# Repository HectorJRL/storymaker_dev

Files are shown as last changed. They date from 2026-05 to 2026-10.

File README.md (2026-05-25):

# StoryMaker

Dispositivo educativo basado en Raspberry Pi Zero 2W para talleres literarios.
Genera premisas narrativas aleatorias y las muestra por pantalla e-ink, impresora térmica o audio.

## Estado
En desarrollo activo. Este repo es el espacio de trabajo privado.

## Estructura
- `firmware/` — Código Python para la Raspberry Pi
- `hardware/` — STL, esquemas eléctricos, lista de componentes
- `docs/` — Manual, guías de montaje, imágenes
- `releases/` — Notas de versión

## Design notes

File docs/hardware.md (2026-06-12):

# Hardware — StoryMaker

## OS
Raspberry Pi OS Lite 64-bit Bookworm (estable)

## Pinout (BCM)
| Función | GPIO |
|---|---|
| Botón físico | 5 |
| LED estado | 23 |
| E-ink DC | 25 |
| E-ink RST | 17 |
| E-ink BUSY | 24 |
| E-ink SPI0 MOSI | 10 |
| E-ink SPI0 CLK | 11 |
| E-ink SPI0 CS0 | 8 |
| Impresora UART TX | 14 |
| Impresora UART RX | 15 |
| Audio I2S BCLK | 18 |
| Audio I2S LRCLK | 19 |
| Audio I2S DATA | 21 |

## Periféricos
- **E-ink:** WeAct 4.2" B&W (SSD1683) — refresco parcial NO soportado
- **Impresora:** QR701 UART térmica (ESC/POS, QR nativo GS(k) modelo 2)
- **Audio:** MAX98357A I2S — TTS edge-tts (es-ES-ElviraNeural) + mpg123
- **Fallback TTS offline:** espeak (voz local, entra cuando no hay red)

## LED (GPIO 23)
- Fijo encendido → sistema listo
- Parpadeo → feedback de pulsación
- Apagado → en proceso de shutdown

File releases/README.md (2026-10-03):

# Releases

Las imágenes distribuibles de StoryMaker (`storymaker-YYYY-MM-DD.img.xz`) **no se versionan en git**:
pesan alrededor de 1 GB. Se publican como **Release assets** en Codeberg. Sí se versiona el fichero
`.sha256` de cada una, que es diminuto y sirve para comprobar después que el adjunto publicado es el
que se generó aquí.

## Dónde descargar la imagen

**Codeberg es el único sitio de descarga.** Sección **Releases** del repositorio →
versión `vYYYY-MM-DD` → fichero `storymaker-YYYY-MM-DD.img.xz`.

`github.com/HectorJRL/storymaker_dev` es **espejo del código, no de las descargas**: los
push-mirrors de Codeberg replican refs de git, y la imagen nunca está en git (la ignora
`.gitignore`). Al espejo llegan los commits y los tags; el `.img.xz` no, porque no hay nada que
copiar.

Decidido así a propósito, y no por dejadez:

- No protege de nada que no esté ya cubierto. El código y la historia completa, tags incluidos, sí
  están en el espejo, y de un tag GitHub genera por su cuenta los `zip`/`tar.gz` del fuente. La
  receta para reconstruir cualquier imagen está duplicada; de la imagen en sí hay dos copias
  (Codeberg y el disco de desarrollo).
- Subir el adjunto al espejo sería un paso manual que nada obliga a repetir, así que se olvidaría
  en alguna release y quedarían unas versiones con descarga allí y otras sin ella: peor que
  ninguna, porque quien busque no sabrá si falta o si nunca se publicó.
- Dos sitios de descarga invitan a bajarse el viejo. El 2026-10-03 hubo que retirar una imagen
  defectuosa pocas horas después de publicarla; con una sola ubicación, retirarla basta.

Si Codeberg fallara: con el tag y el proceso descrito más abajo, la imagen se reconstruye.

## Credenciales de fábrica

| Credencial | De fábrica | Quién la cambia |
|---|---|---|
| PIN del portal web | `1234` | El usuario en el asistente de primer arranque (opcional) |
| Contraseña SSH de `storymaker` | `storymaker` | El usuario en el asistente de primer arranque (**obligatoria**) |

Son conocidas y públicas a propósito: el asistente no deja completar la configuración sin definir una
contraseña SSH propia, así que cada dispositivo acaba con la suya. Ver `docs/sistema.md`.

## Cómo publicar una release nueva

El orden importa. Lo que sigue es el proceso verificado el 2026-10-03.

### 1. Antes de tocar la imagen

```bash
git pull                                  # que no haya divergencia con el espejo
./deploy.sh <ip-de-la-pi>                 # el firmware debe ser el que vas a congelar
./deploy.sh --solo-firmware <ip-de-la-pi> # si sólo ha cambiado código Python
```

Desde v2026-10-03 las imágenes no traen el `NOPASSWD: ALL` de Raspberry Pi OS, así que instalar
ficheros de sistema pide la contraseña del dispositivo; ese paso usa `ssh -t` para que `sudo` tenga
terminal. Si sólo ha cambiado código Python —compruébalo con
`git diff --name-only <tag-de-la-imagen>..HEAD -- firmware/deploy/sistema/`— usa `--solo-firmware` y
te lo ahorras: reiniciar `historias.service` sí está en la lista corta de `/etc/sudoers.d`.

Prueba en el dispositivo lo que hayas cambiado. Una imagen se publica desde una Pi cuyo
comportamiento has visto funcionar, no desde una que asumes correcta.

### 2. Limpieza y captura

```bash
cd firmware/deploy
./crear_imagen.sh --local     # con la SD ya en el PC y la Pi apagada
./crear_imagen.sh <ip>        # o con la Pi encendida: limpia por SSH y la apaga
```

**Verifica la tarjeta antes de capturar.** Monta la raíz en sólo lectura y comprueba que no quedan
claves de host SSH, que `authorized_keys` y `.bash_history` están vacíos, que `010_pi-nopasswd` ha
desaparecido, que `storymaker-setpass` está instalado, que sólo queda el perfil de red del AP y que
`config.json` tiene `setup_completado: false`. Ese paso es el que detecta los fallos de limpieza; en
junio de 2026 no se hacía y la limpieza llevaba meses ejecutándose a medias sin que nadie lo notara.

En modo `--local` se ejecuta además `limpiar_montada.sh` en frío sobre la tarjeta, que **resetea los
interruptores de hardware a desactivado**. `limpiar_pi.sh` no lo hace. Esa divergencia es conocida.

> Tras la captura, la tarjeta se queda con el sistema de ficheros encogido al mínimo y **sin** el
> gancho de autoexpansión, que `pishrink` añade a la imagen y no a la tarjeta. Reflashea la SD con la
> imagen generada antes de volver a usar esa Pi.

### 3. Checksum y tag

```bash
mv storymaker-$(date +%F).img.xz releases/
cd releases && sha256sum storymaker-*.img.xz | tee storymaker-*.img.xz.sha256
git add releases/*.sha256 && git commit && git push
git tag -a vYYYY-MM-DD        # el SHA256 va en el mensaje del tag
git push origin vYYYY-MM-DD
```

### 4. Publicar

Con el CLI [`tea`](https://dl.gitea.com/tea/) autenticado (`tea login add --name codeberg --url
https://codeberg.org --token <TOKEN>`, permiso `write:repository`):

```bash
tea release create --login codeberg --repo Profektor/storymaker_dev \
    --tag vYYYY-MM-DD --title "StoryMaker vYYYY-MM-DD" --note "$(cat notas.md)"
tea releases assets create --login codeberg --repo Profektor/storymaker_dev \
    vYYYY-MM-DD releases/storymaker-*.img.xz releases/storymaker-*.img.xz.sha256
```

`tea` no imprime nada al crear una release. Comprueba el resultado:

```bash
tea api --login codeberg "repos/Profektor/storymaker_dev/releases"
```

### 5. Espejo

Los push-mirrors replican cada 8 horas. Para no esperar:

```bash
tea api --method POST --login codeberg "repos/Profektor/storymaker_dev/push_mirrors-sync"
```

Y confirma que ha llegado, en lugar de suponerlo:

```bash
curl -s https://api.github.com/repos/HectorJRL/storymaker_dev/commits/main | grep '"sha"'
```

Al espejo llegan commits y tags, no los adjuntos. No hace falta hacer nada con ellos allí: ver
«Dónde descargar la imagen» arriba.

Si se retira una release ya publicada —por ejemplo porque la imagen salió con un fallo—,
`tea release delete -y --delete-tag <tag>` borra release y tag de una vez, y el espejo recoge la
desaparición del tag en la siguiente sincronización. Conviene comprobar antes las descargas del
adjunto (`tea api --login codeberg "repos/.../releases"`) para saber a cuánta gente afecta.

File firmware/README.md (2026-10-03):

# StoryMaker — Firmware

Código Python que corre en la Raspberry Pi Zero 2W. Gestiona el botón físico,
las salidas (e-ink, impresora térmica, audio) y el portal web de configuración.

## Requisitos

- Raspberry Pi OS Lite 64-bit (Bookworm)
- Python 3.11+
- Entorno virtual en `proyecto/venv/`

## Estructura

firmware/
├── main.py              # Punto de entrada. Inicializa hardware y bucle principal
├── config.json          # Configuración activa (hardware, perfil, portal, PIN)
├── modules/
│   ├── boton.py         # Polling GPIO: pulsación corta/larga + LED
│   ├── eink.py          # Pantalla e-ink WeAct 4.2" (SSD1683, SPI0)
│   ├── audio.py         # Síntesis de voz edge-tts + reproducción mpg123
│   ├── impresora.py     # Impresora térmica QR701 UART (ESC/POS)
│   ├── generador.py     # Generador de premisas aleatorias desde perfiles .txt
│   ├── importador.py    # Importación masiva de premisas desde .txt (limpieza + copias)
│   ├── salidas.py       # Orquesta las salidas activas + animación e-ink
│   ├── portal.py        # Portal web Flask (puerto 5000): configuración y generación
│   ├── config_manager.py# Lectura/escritura atómica de config.json (thread-safe)
│   ├── netinfo.py       # Detecta modo de red (client/AP/none) para impresora/eink
│   └── init.py
└── data/
├── config.json          # Configuración activa
├── pluma.png            # Animación "pensando" para e-ink
├── logo_atrapa.png      # Logo del taller
└── perfiles/
└── 1eso/            # Perfil de ejemplo (1º ESO)
├── detonantes.txt
├── protagonistas.txt
└── conflictos.txt

## Salidas disponibles

| Salida | Módulo | Interfaz |
|---|---|---|
| Pantalla e-ink | eink.py | SPI0 (GPIO 10/11/8) + DC/RST/BUSY |
| Impresora térmica | impresora.py | UART (/dev/serial0, 9600 baud) |
| Audio | audio.py | I2S MAX98357A (GPIO 18/19/21) |

## Perfiles

Cada perfil es una carpeta en `data/perfiles/<nombre>/` con tres archivos .txt,
uno por línea: `detonantes.txt`, `protagonistas.txt`, `conflictos.txt`.
El perfil activo se configura en `config.json` → `perfil_activo`.

### Importar premisas en bloque

Desde el portal, `⇪ Importar .txt` (barra lateral, o en la cabecera de cualquier
lista de premisas) abre un asistente de tres pasos en `/importar`:

1. **Destino** — un perfil existente, o uno nuevo que se crea en el momento
   (con opción de dejarlo como perfil activo al terminar).
2. **Modo** — *añadir al final* (por defecto) o *reemplazar la lista*. En un
   perfil nuevo el paso no aplica.
3. **Textos** — un `.txt` por categoría, o la lista pegada a mano. Si se
   rellenan ambos para la misma categoría, se concatenan. Las categorías que se
   dejan vacías no se modifican.

Antes de escribir nada se muestra una **revisión**: cuántas frases entran, qué
se descarta (repetidas, ya existentes, demasiado largas) y cómo queda cada
categoría. Al confirmar se guarda un `<tipo>.txt.bak` por categoría tocada, de
modo que el botón **Deshacer** devuelve las listas a su estado anterior
(un solo nivel: la siguiente importación lo sustituye).

Si el destino es el perfil activo, el `Generador` se recarga al confirmar, lo
que reinicia el recuento de combinaciones de la sesión en curso.

Límites: 3 MB por envío, 5000 frases por categoría, 300 caracteres por frase.

## Despliegue

Ver `deploy/sistema/README.md` para los pasos completos.
El servicio systemd se llama `historias.service` y corre como usuario `storymaker`.

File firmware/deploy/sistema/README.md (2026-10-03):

# StoryMaker — Archivos de sistema

Estos archivos van fuera del directorio del proyecto porque requieren
permisos de root o pertenecen a servicios del sistema operativo.
Hay que aplicarlos manualmente en cada despliegue limpio.

## Archivos y destinos

| Archivo | Destino en la Pi | Descripción |
|---|---|---|
| `historias.service` | `/etc/systemd/system/` | Servicio principal: arranca el proyecto Python |
| `storymaker-wifi.service` | `/etc/systemd/system/` | Gestiona WiFi al arrancar (cliente o AP) |
| `storymaker-captive.service` | `/etc/systemd/system/` | Portal cautivo Flask en puerto 8080 |
| `storymaker-wifi.sh` | `/usr/local/bin/` | Script de gestión WiFi |
| `storymaker-captive.py` | `/usr/local/bin/` | Portal cautivo para configurar WiFi desde el AP |
| `storymaker-shutdown` | `/etc/sudoers.d/` | Permisos NOPASSWD: shutdown, restart del servicio y setpass |
| `storymaker-setpass` | `/usr/local/bin/` | Fija la contraseña SSH del dispositivo; lo invoca el portal por sudo |

## Orden de aplicación en una SD nueva

### 1. Sudoers
```bash
sudo cp storymaker-shutdown /etc/sudoers.d/
sudo chmod 440 /etc/sudoers.d/storymaker-shutdown
```

### 2. Scripts WiFi y portal cautivo
```bash
sudo cp storymaker-wifi.sh /usr/local/bin/
sudo cp storymaker-captive.py /usr/local/bin/
sudo chmod +x /usr/local/bin/storymaker-wifi.sh
sudo chmod +x /usr/local/bin/storymaker-captive.py
```

### 3. Servicios systemd
```bash
sudo cp historias.service          /etc/systemd/system/
sudo cp storymaker-wifi.service    /etc/systemd/system/
sudo cp storymaker-captive.service /etc/systemd/system/
sudo systemctl daemon-reload
sudo systemctl enable storymaker-wifi.service
sudo systemctl enable storymaker-captive.service
sudo systemctl enable historias.service
```

### 4. Reglas iptables (portal cautivo)

Estas reglas redirigen el tráfico HTTP del AP al portal cautivo para que
iOS, Android y Windows muestren la pantalla de configuración WiFi
automáticamente al conectarse.

```bash
# Redirigir HTTP (80) → portal cautivo (8080) solo en la interfaz AP
sudo iptables -t nat -A PREROUTING -i wlan0 -p tcp --dport 80 -j REDIRECT --to-port 8080

# Persistir las reglas para que sobrevivan reinicios
sudo apt-get install -y netfilter-persistent iptables-persistent
sudo netfilter-persistent save
```

> **Nota:** Sin estas reglas el portal cautivo escucha en :8080 pero los sistemas
> operativos hacen el chequeo de captive portal en el puerto 80 — sin la redirección
> nunca detectan que hay portal y no muestran la pantalla de configuración.

### 5. Configuración adicional del sistema

- **SPI habilitado**: `sudo raspi-config nonint do_spi 0`
- **I2S audio** (si se usa el MAX98357A): añadir `dtoverlay=hifiberry-dac` a `/boot/config.txt`
- **UART habilitado** (impresora): `sudo raspi-config nonint do_serial_hw 0` y deshabilitar login serial
- **NetworkManager**: sin `wifi.backend=nl80211` en `/etc/NetworkManager/conf.d/`
- **NetworkManager-wait-online deshabilitado**: `sudo systemctl disable NetworkManager-wait-online.service`
- **avahi-daemon**: para resolución mDNS → `storymaker.local:5000`
- **Usuario del sistema**: `storymaker` (uid 1000), dueño de `/home/storymaker/proyecto`
- **Perfil AP en NetworkManager**: crear la conexión `StoryMaker-Setup` como hotspot abierto en 10.42.0.1

## Red WiFi — modo de operación

| Situación | Comportamiento | Acceso |
|---|---|---|
| WiFi conocida en alcance | Conecta como cliente | `http://storymaker.local:5000` |
| Sin red conocida | Levanta AP `StoryMaker-Setup` | Conectar al AP → captive portal en `:8080` |

### QR en modo AP
El QR impreso y en pantalla apunta a `http://10.42.0.1:8080` (portal cautivo).
Desde ahí se selecciona la red WiFi y se introduce la contraseña.
Una vez conectado, el dispositivo recuerda la red para futuros arranques.

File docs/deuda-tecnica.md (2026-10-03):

# Deuda técnica conocida

- **Renombrar el perfil `1eso` a `juvenil`, en la próxima release.** `1eso` sólo
  significa algo dentro del sistema educativo español; `juvenil` cubre el mismo
  tramo de edad sin atarse a una nomenclatura nacional, y quien necesite algo más
  concreto se lo crea desde el portal, que justamente está diseñado para eso.
  Decidido el 2026-10-03 y dejado fuera de v2026-10-03 a propósito.
  Hay que cambiarlo en seis sitios:
  - `git mv firmware/data/perfiles/1eso firmware/data/perfiles/juvenil`
  - `firmware/data/config.json` → `perfil_activo`
  - `firmware/data/config.template.json` → `perfil_activo`
  - `firmware/deploy/limpiar_pi.sh` → `PERFIL_FABRICA`
  - `firmware/deploy/limpiar_montada.sh` → `PERFIL_FABRICA`
  - `firmware/README.md` → el árbol de `data/`

  Los dispositivos ya en campo no se rompen: `deploy.sh` excluye `data/perfiles/`
  y `data/config.json`, así que conservan su carpeta `1eso` y su configuración.
  El cambio sólo afecta a lo que traiga una imagen nueva o una instalación hecha
  con `setup_sd.sh`.

- **Codeberg arrastra ~976 MB de un blob huérfano.** La imagen
  `storymaker-2026-06-23.img.xz` se subió en su día dentro del repo; al reescribir
  la historia para quitarla, el objeto quedó allí sin ninguna referencia que lo
  apunte (`git ls-remote` sólo devuelve `main`). Los objetos inalcanzables no se
  envían al clonar, así que no afecta a quien clone, pero ocupa disco en Codeberg
  y cuenta para su cuota. Sólo lo puede eliminar el `git gc` del servidor, que no
  es accesible por API: hay que pedirlo en `codeberg.org/Codeberg/Community`. El
  espejo de GitHub se libró (0,4 MB).
- **Divergencia entre los dos scripts de limpieza.** `limpiar_montada.sh` resetea
  los interruptores de hardware a desactivado y `limpiar_pi.sh` no. Como
  `crear_imagen.sh --local` ejecuta el primero, el resultado depende del modo de
  captura. Decidido el 2026-10-03 dejarlo así, pero conviene unificarlo.
- Eleven Labs como opción TTS premium (no implementado)
- **Sin internet, cada frase pierde 15 s esperando a edge-tts.** `audio.py`
  decide el motor con `self._edge_ok = os.path.isfile(EDGE_TTS_BIN)`, que sólo
  mira si existe el binario: nunca comprueba la red, pese a que el mensaje de
  arranque diga «Sin red o edge-tts no disponible». Resultado: en una zona sin
  internet, `hablar()` intenta edge-tts en cada premisa y agota el
  `asyncio.wait_for(..., timeout=15.0)` antes de caer a `espeak-ng`. Funciona,
  pero con 15 s de silencio por frase el dispositivo parece averiado.
  Dos arreglos que se complementan: usar `netinfo.get_wifi_mode()` —ya existe y
  main.py lo usa para la bienvenida— para descartar edge-tts cuando no hay ruta;
  y recordar el fallo unos minutos, de modo que tras el primer timeout las frases
  siguientes vayan directas a espeak en lugar de reintentar cada vez.
  Relevante para talleres en sitios sin cobertura, que es un escenario de uso
  previsto.
- **La bienvenida de la e-ink en modo AP no dice a qué red conectarse.** Muestra
  un QR con `http://10.42.0.1:8080` y el texto «Escanea el QR para configurar el
  WiFi», pero ese portal no es alcanzable hasta estar conectado a la red
  `StoryMaker-Setup`, cuyo nombre no aparece en ninguna parte de la pantalla. El
  2026-10-03 se corrigió el equivalente en la impresora térmica, que ahora numera
  los pasos y pone el nombre de la red en negrita antes del QR; la e-ink sigue
  pendiente porque toca su composición gráfica. Mejor aún para las dos salidas
  sería un QR de tipo `WIFI:S:StoryMaker-Setup;T:nopass;;`, que los móviles usan
  para unirse a la red directamente; tras eso el portal cautivo se abre solo.
- **Contraseña SSH en claro sobre el AP de configuración.** El asistente de
  primer arranque pide la contraseña por HTTP y, cuando no hay red conocida, eso
  ocurre sobre el AP abierto `StoryMaker-Setup`. Alternativa valorada y no
  implementada: generar una contraseña fuerte en el dispositivo y mostrarla en la
  e-ink o imprimirla, de modo que no cruce ninguna red. Mitigación actual: la
  ventana es un único primer arranque, y si se configura ya conectado a una red
  WPA2 el problema desaparece.
- **La imagen podría salir con la contraseña bloqueada en vez de con una de
  fábrica.** `passwd -l storymaker` dejaría la imagen sin ninguna credencial SSH
  utilizable hasta que el asistente fije una, lo que elimina del todo la ventana
  anterior. No se hizo porque obliga a encadenar bloqueo y apagado en la misma
  sesión SSH durante la captura, y un fallo a medias deja la Pi de desarrollo sin
  acceso. Revisable cuando el proceso de imagen esté más automatizado.
- **El importador deja tres `.txt.bak` de 0 bytes al crear un perfil nuevo.**
  `crear_perfil` escribe los `.txt` vacíos y `aplicar()` los respalda antes de
  poblarlos. Es inocuo y hace que «Deshacer» devuelva el perfil a recién creado,
  pero ensucia la carpeta. Los scripts de limpieza los borran, así que no viajan
  en la imagen.
- `journald Storage=volatile` configurado en `setup_sd.sh` (paso 2) — solo afecta a installs nuevas; la Pi de desarrollo existente sigue en `persistent` hasta nuevo deploy

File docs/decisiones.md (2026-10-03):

# Decisiones técnicas

- GPIO con `RPi.GPIO` + polling software (sin lgpio, sin gpiozero, sin edge detection)
- SPI fragmentado a 4000 bytes para evitar `OverflowError`
- `eink.py` usa secuencia de inicialización SSD1683 WeAct oficial (no Waveshare)
- Audio TTS: `edge-tts` genera MP3 → `mpg123` reproduce
- `config_manager.py` usa lock + escritura atómica para evitar corrupción JSON concurrente
- Animación e-ink: `pluma.png` pre-renderizada al arrancar; se muestra mientras genera
- Portal web: slider volumen con debounce 400ms; restart servicio via `subprocess.Popen` con `start_new_session=True`
- `journald`: Storage=auto (volátil) — no saturar SD en producción
- Contraseña SSH por dispositivo: el asistente de primer arranque la exige y la
  aplica con el ayudante privilegiado `storymaker-setpass`
  - El problema que resuelve: la imagen distribuible es pública, así que la
    contraseña que lleve dentro es una credencial compartida por todas las
    unidades. Y con `NOPASSWD: ALL`, entrar por SSH era ser root directo: con
    eso se leen los `psk=` en claro de `/etc/NetworkManager/system-connections/`,
    o sea la clave WiFi de la red donde esté el aparato
  - Se eligió pedirla en `/setup` en vez de generarla y mostrarla en la e-ink,
    para que sea memorizable; el coste es que sobre el AP abierto viaja en claro
  - La contraseña va por *stdin* al ayudante, nunca como argumento (`ps`), el
    usuario está fijado dentro del script (no vale `sudo chpasswd` a secas) y la
    validación se repite en el script por ser la frontera de privilegio
  - `limpiar_*.sh` abortan si falta el ayudante o su línea de sudoers: una imagen
    sin ellos y sin `010_pi-nopasswd` dejaría el dispositivo inservible, porque
    el asistente no podría cumplir un requisito que es obligatorio
- Importación de premisas (`importador.py`): flujo de tres pantallas
  (formulario → revisión → confirmación) porque el usuario final no es técnico;
  nada se escribe hasta confirmar
  - Decodifica UTF-8/BOM y reintenta CP1252 y Latin-1: los .txt llegan de Word
    y del Bloc de notas de Windows
  - Deduplica sin distinguir mayúsculas ni espacios múltiples, pero **no** toca
    la puntuación: el `Generador` ya recorta la final al cargar
  - Copia `<tipo>.txt.bak` antes de escribir → botón «Deshacer» de un nivel
  - Las categorías que el usuario deja vacías no se tocan, ni en modo reemplazar
  - Avisa si una categoría quedaría a cero: el `Generador` lanza `ValueError`
    con una lista vacía y `main.py` se quedaría con el perfil anterior en silencio
  - Al importar sobre el perfil activo se recarga el `Generador` reutilizando
    `_callback_cambiar_perfil`; eso reinicia el contador de combinaciones y el
    portal lo avisa
  - Revisión pendiente en memoria (token + sesión, 15 min), no en campos ocultos:
    menos RAM y menos tráfico en la Pi Zero
  - `MAX_CONTENT_LENGTH` 3 MB; 5000 líneas y 300 caracteres por línea

## Estructura interna de firmware/
```
firmware/
├── main.py
├── config.json
├── config_manager.py
├── modules/
│   ├── boton.py
│   ├── eink.py
│   ├── impresora.py
│   ├── audio.py
│   ├── salidas.py
│   ├── generador.py
│   ├── importador.py
│   └── portal.py
├── data/
│   ├── pluma.png
│   └── perfiles/<nombre>/{detonantes,protagonistas,conflictos}.txt
└── deploy/
    └── deploy.sh   # SSH+sshpass, sube por /tmp
```

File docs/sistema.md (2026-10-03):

# Configuraciones del sistema (fuera del repo)

Todo lo que `setup_sd.sh` instala automáticamente. Esta doc es referencia, no pasos manuales.

## Archivos instalados por setup_sd.sh

| Archivo en repo | Destino en Pi | Descripción |
|---|---|---|
| `deploy/sistema/historias.service` | `/etc/systemd/system/` | Servicio principal Python |
| `deploy/sistema/storymaker-wifi.service` | `/etc/systemd/system/` | Gestiona WiFi al arrancar |
| `deploy/sistema/storymaker-captive.service` | `/etc/systemd/system/` | Portal cautivo (puerto 8080) |
| `deploy/sistema/storymaker-wifi.sh` | `/usr/local/bin/` | Script gestión WiFi (cliente/AP) |
| `deploy/sistema/storymaker-captive.py` | `/usr/local/bin/` | Portal cautivo Flask |
| `deploy/sistema/storymaker-shutdown` | `/etc/sudoers.d/` | NOPASSWD: shutdown, restart servicio y setpass |
| `deploy/sistema/storymaker-setpass` | `/usr/local/bin/` | Fija la contraseña SSH del dispositivo (lo llama el portal) |

## Acceso y credenciales

| Credencial | De fábrica | Quién la cambia |
|---|---|---|
| PIN del portal web | `1234` | El usuario, en el asistente de primer arranque (opcional) |
| Contraseña SSH de `storymaker` | `storymaker` | El usuario, en el asistente de primer arranque (**obligatoria**) |

La imagen distribuible sale con esas dos credenciales conocidas y documentadas.
El asistente `/setup` **no deja completar la configuración** sin definir una
contraseña SSH propia, de forma que cada dispositivo acabe con la suya en lugar
de compartir todas las unidades la que viaja dentro de la imagen publicada.

El cambio lo aplica `/usr/local/bin/storymaker-setpass`, invocado por el portal
vía `sudo` con una línea NOPASSWD. La contraseña le llega por *stdin*, nunca
como argumento (sería visible en `ps`), y el usuario va fijado dentro del script
porque permitir `sudo chpasswd` a secas dejaría cambiar la de cualquier cuenta,
root incluida.

`setup_sd.sh` y los dos scripts de limpieza **eliminan
`/etc/sudoers.d/010_pi-nopasswd`**, el `NOPASSWD: ALL` que Raspberry Pi OS
instala de serie. Sin ese recorte, entrar por SSH equivale a ser root y la
contraseña propia serviría de poco. Quedan permitidas sin contraseña sólo las
tres órdenes de `storymaker-shutdown`; `sudo` sigue funcionando para lo demás
pidiendo la contraseña.

> Limitación conocida: el asistente corre sobre HTTP y, en el primer arranque
> sin red conocida, sobre el AP abierto `StoryMaker-Setup`. En ese escenario la
> contraseña viaja en claro por una WiFi sin cifrar. Ver `deuda-tecnica.md`.

## Red / WiFi

- NetworkManager gestiona wlan0
- mDNS via avahi → `storymaker.local:5000`
- Sin red conocida → AP "StoryMaker-Setup" (abierto, 10.42.0.1)
- Portal cautivo Flask en puerto 8080; iptables redirige 80→8080
- Script: `/usr/local/bin/storymaker-wifi.sh`

## Servicios habilitados

```
historias.service          # arranca con el sistema
storymaker-wifi.service    # antes de historias
storymaker-captive.service # siempre activo (solo responde en modo AP)
avahi-daemon               # mDNS → storymaker.local
NetworkManager-wait-online # DESHABILITADO (arranque más rápido)
```

## Otros ajustes configurados

- SPI habilitado (`dtparam=spi=on` en `config.txt`)
- UART estable para impresora (`enable_uart=1` + `dtoverlay=disable-bt`)
- I2S audio (`dtoverlay=hifiberry-dac`)
- Consola serie eliminada de cmdline.txt (UART libre para impresora)
- `storymaker` en grupos: spi, gpio, dialout, audio
- `/etc/asound.conf` con `dmix` para MAX98357A (evita chasquido entre premisas)
- Perfil AP en NetworkManager: "StoryMaker-Setup", 10.42.0.1, modo infrastructure/ap
- iptables: `PREROUTING -i wlan0 -p tcp --dport 80 → :8080` (captive portal)

---

## Flujo de deploy completo (SD nueva desde cero)

### Paso 1 — Flashear SD

Flashear con **Raspberry Pi Imager**:
- Modelo: Raspberry Pi Zero 2W
- SO: Raspberry Pi OS Lite (64-bit, Bookworm)
- **No personalizar** (Bookworm en Imager trata la imagen como Debian genérico y bloquea la personalización)

### Paso 2 — Preparar SD desde el PC

Con la SD en el lector conectado al PC:

```bash
# Identificar dispositivo
lsblk -o NAME,SIZE,LABEL,MOUNTPOINT | grep -v loop

# Configurar: escribe usuario, hostname, SSH y WiFi directamente en la SD
sudo firmware/deploy/prepare_sd.sh /dev/sdX "NombreWiFi" "ContraseñaWiFi"
```

`prepare_sd.sh` crea: `boot/ssh`, `boot/userconf.txt` (usuario storymaker), `/etc/hostname`, perfil NM en `/etc/NetworkManager/system-connections/`.

### Paso 3 — Primer arranque

Insertar SD en Pi Zero 2W y encender. La Pi conecta sola a la WiFi configurada.

Conectar por SSH (~60 s después de encender):
```bash
ssh storymaker@storymaker.local
# o por IP si mDNS no responde:
# ssh storymaker@<ip-del-router>
```

### Paso 4 — Setup automático

```bash
cd firmware/deploy
./setup_sd.sh <ip-de-la-pi>
```

Instala paquetes, habilita hardware, servicios, venv Python, despliega firmware. Reinicia la Pi al final.

### Paso 5 — Verificar

Tras el reboot (~30 s):
```bash
# Portal de control
http://storymaker.local:5000   # → login (PIN: 1234) → wizard hardware
```

---

## Flujo de actualización (deploy incremental)

Solo actualiza código Python, conserva `config.json` y `data/perfiles/`:

```bash
cd firmware/deploy
./deploy.sh <ip-de-la-pi>
```

---

## Flujo de imagen distributable

Para crear una imagen `.img.xz` lista para distribuir en Codeberg Releases:

```bash
# Prerequisito: pishrink.sh en PATH del host
# wget https://raw.githubusercontent.com/Drewsif/PiShrink/master/pishrink.sh
# chmod +x pishrink.sh && sudo mv pishrink.sh /usr/local/bin/

cd firmware/deploy
./crear_imagen.sh <ip-de-la-pi>
```

Limpia la Pi (WiFi, config, claves SSH, logs), apaga, captura con `dd`, reduce con `pishrink`, comprime con `xz`. Deja `storymaker-YYYY-MM-DD.img.xz` en la raíz del proyecto.

---

## Flujo de primer arranque desde imagen distributable

El usuario final (sin conocimientos técnicos) hace:

1. Descargar `storymaker-YYYY-MM-DD.img.xz` de Codeberg Releases
2. Abrirlo con Raspberry Pi Imager → "Usar imagen personalizada" → flashear
3. Insertar SD en Pi y encender
4. Conectar su móvil/portátil al AP **"StoryMaker-Setup"** (WiFi sin contraseña)
5. El navegador abre solo el portal cautivo (puerto 8080) → seleccionar red WiFi → conectar
6. La pantalla de éxito muestra la URL del paso 2: `http://storymaker.local:5000`
7. Reconectar el móvil a la WiFi habitual → abrir esa URL
8. Login con PIN **1234** (hay un aviso en pantalla) → wizard de hardware → listo

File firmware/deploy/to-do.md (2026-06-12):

# TO-DO LIST en el firmware

## Pendiente
- Comprobar si Claude-code puede recrear el firmware para trixie.
- Incluir ip en pantalla bienvenida (e-ink y portal).
- **[e-ink]** Ajustar renderizado de texto para premisas largas: texto se sale de la pantalla. Revisar cálculo de tamaño de fuente dinámico y wrap en `modules/eink.py`.
- Añadir audio de bienvenida y despedida.

## Hecho
- Wizard de primer arranque: portal cautivo muestra paso 2 tras conectar WiFi, con URL y pin inicial.
- Login portal: aviso de PIN inicial (1234) cuando `setup_completado=false`.
- Fix: modelo e-ink SSD1619 → SSD1683 en página de setup.
- Scripts de imagen distributable: `limpiar_pi.sh` + `crear_imagen.sh`.

## Flujo de actualización / imagen
1. Modificar código en rama dev → commit → push a Codeberg (repo dev).
2. Deploy en Pi de prueba: `./deploy.sh <ip>` y verificar.
3. Cuando todo OK: `./crear_imagen.sh <ip>` → genera `storymaker-YYYY-MM-DD.img.xz`.
4. Subir imagen a Codeberg Releases del repo público (release vYYYY-MM-DD).

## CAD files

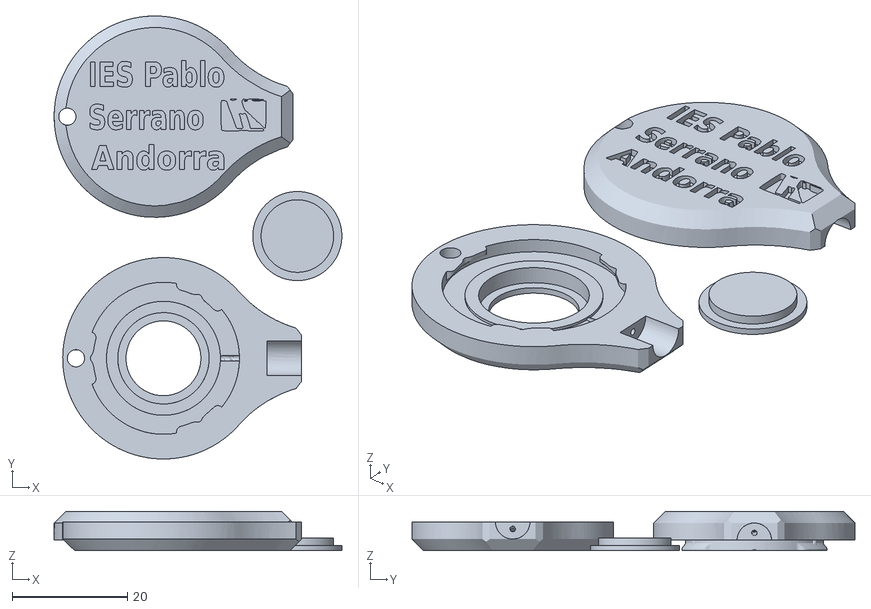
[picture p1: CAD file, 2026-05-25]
hardware/stl/Linterna logo IES.stl
50.0 x 77.0 x 6.80

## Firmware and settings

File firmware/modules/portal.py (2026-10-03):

#!/usr/bin/env python3
"""
portal.py — Interfaz web de gestión StoryMaker.
Rutas:
  /             → panel principal (requiere login)
  /login        → formulario PIN
  /logout
  /setup        → configuración de hardware (primer arranque)
  /perfil/<n>/<tipo>  → ver/editar premisas
  /importar     → importar premisas en bloque desde .txt (3 pasos)
  /api/*        → endpoints JSON
Se lanza en un hilo separado (daemon) para no bloquear main.py.
"""
import html
import os
import secrets
import tempfile
import threading
import time
from functools import wraps
from flask import Flask, request, session, redirect, url_for, jsonify
from modules.config_manager import cargar_config, guardar_config
from modules import importador

BASE_DIR     = os.path.join(os.path.dirname(__file__), '..')
PERFILES_DIR = os.path.join(BASE_DIR, 'data', 'perfiles')
PIN_DEFAULT  = "1234"

# Contraseña UNIX con la que sale la imagen distribuible. El asistente de primer
# arranque obliga a cambiarla: así cada dispositivo tiene la suya y no comparten
# todos la credencial que viaja dentro de la imagen publicada.
PASS_FABRICA  = "storymaker"
MIN_PASS_SSH  = 8
SETPASS_BIN   = "/usr/local/bin/storymaker-setpass"

app = Flask(__name__)
# Secret temporal hasta que Portal.__init__ cargue el valor persistente de config.json
app.secret_key = secrets.token_hex(32)

# Tope de subida para la importación de premisas. 3 MB son decenas de miles de
# frases; el límite está para que un archivo enorme no agote la RAM de la Pi Zero.
app.config['MAX_CONTENT_LENGTH'] = 3 * 1024 * 1024

# Callback de generación registrado desde main.py
_callback_generar = None

def registrar_callback_generar(cb):
    global _callback_generar
    _callback_generar = cb

_callback_despedida = None

def registrar_callback_despedida(cb):
    global _callback_despedida
    _callback_despedida = cb

_callback_cambiar_perfil = None

def registrar_callback_cambiar_perfil(cb):
    global _callback_cambiar_perfil
    _callback_cambiar_perfil = cb

# ------------------------------------------------------------------ #
# Helpers                                                             #
# ------------------------------------------------------------------ #
def get_perfiles():
    ruta = os.path.abspath(PERFILES_DIR)
    if not os.path.exists(ruta):
        return []
    return sorted([d for d in os.listdir(ruta) if os.path.isdir(os.path.join(ruta, d))])

def get_premisas(perfil, tipo):
    ruta = os.path.abspath(os.path.join(PERFILES_DIR, perfil, f"{tipo}.txt"))
    if not os.path.exists(ruta):
        return []
    with open(ruta, 'r', encoding='utf-8') as f:
        return [l.strip() for l in f if l.strip()]

def guardar_premisas(perfil, tipo, premisas):
    """Escritura atómica: escribe en temporal y renombra.
    Evita corrupción si la SD se llena o el sistema pierde alimentación a mitad."""
    ruta = os.path.abspath(os.path.join(PERFILES_DIR, perfil, f"{tipo}.txt"))
    directorio = os.path.dirname(ruta)
    fd, tmp = tempfile.mkstemp(dir=directorio, suffix='.tmp')
    try:
        with os.fdopen(fd, 'w', encoding='utf-8') as f:
            f.write('\n'.join(premisas) + ('\n' if premisas else ''))
        os.replace(tmp, ruta)       # atómico en Linux
    except Exception:
        try:
            os.unlink(tmp)
        except OSError:
            pass
        raise

def _comprobar_pass(nueva, repite, obligatoria):
    """Valida la contraseña SSH escrita en el asistente.
    Devuelve None si es aceptable, o el mensaje a mostrar al usuario."""
    if not nueva and not repite:
        if obligatoria:
            return ("Define una contraseña para el acceso SSH de este dispositivo. "
                    "Es lo que evita que todos los StoryMaker compartan la misma "
                    "contraseña de fábrica.")
        return None
    if nueva != repite:
        return "Las dos contraseñas no coinciden. Vuelve a escribirlas."
    if len(nueva) < MIN_PASS_SSH:
        return f"La contraseña debe tener al menos {MIN_PASS_SSH} caracteres."
    if any(c.isspace() for c in nueva):
        return "La contraseña no puede contener espacios ni tabuladores."
    if nueva == PASS_FABRICA:
        return "Esa es justo la contraseña de fábrica. Elige otra distinta."
    return None


def _fijar_pass_ssh(nueva):
    """Cambia la contraseña UNIX de `storymaker` con el ayudante privilegiado.

    La contraseña va por stdin: como argumento sería visible en `ps` para
    cualquier usuario de la máquina. No se registra en ningún sitio.
    Devuelve (ok, mensaje_de_error)."""
    import subprocess
    try:
        r = subprocess.run(['sudo', '-n', SETPASS_BIN],
                           input=nueva + '\n', text=True,
                           capture_output=True, timeout=20)
    except FileNotFoundError:
        return False, ("No se encuentra el ayudante del sistema que cambia la "
                       "contraseña. Revisa la instalación del dispositivo.")
    except Exception as e:
        return False, f"No se ha podido cambiar la contraseña del sistema: {e}"
    if r.returncode != 0:
        lineas = (r.stderr or '').strip().splitlines()
        pista  = lineas[-1] if lineas else f"código {r.returncode}"
        return False, f"El sistema ha rechazado la contraseña: {pista}"
    return True, ''


def login_requerido(f):
    @wraps(f)
    def decorated(*args, **kwargs):
        if not session.get('autenticado'):
            return redirect(url_for('login'))
        return f(*args, **kwargs)
    return decorated

# ------------------------------------------------------------------ #
# Auth                                                                #
# ------------------------------------------------------------------ #
@app.route('/login', methods=['GET', 'POST'])
def login():
    error = None
    config = cargar_config()
    if request.method == 'POST':
        if request.form.get('pin') == config.get('pin', PIN_DEFAULT):
            session['autenticado'] = True
            if not config.get('setup_completado', False):
                return redirect(url_for('setup'))
            return redirect(url_for('index'))
        error = "PIN incorrecto"
    primer_arranque = not config.get('setup_completado', False)
    return _render_login(error, primer_arranque)

@app.route('/api/generar', methods=['POST'])
@login_requerido
def api_generar():
    if _callback_generar is None:
        return jsonify({'ok': False, 'error': 'Sistema no listo'})
    try:
        threading.Thread(target=_callback_generar, daemon=True).start()
        return jsonify({'ok': True})
    except Exception as e:
        return jsonify({'ok': False, 'error': str(e)})

@app.route('/logout')
def logout():
    session.clear()
    return redirect(url_for('login'))
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

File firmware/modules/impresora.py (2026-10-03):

"""
impresora.py — Comunicación con la impresora térmica QR701-N32 vía UART.
Firmware GB18030/PC936 sin posibilidad de cambio de codificación.
Solución: transliteración a ASCII + cancelación modo chino.
Pinout UART:
  GPIO14 → TX  (/dev/serial0)
"""
import time
import textwrap
try:
    import serial
    SERIAL_DISPONIBLE = True
except ImportError:
    SERIAL_DISPONIBLE = False
    print("[Impresora] AVISO: pyserial no disponible. Modo simulación activo.")

# Tabla de transliteración: caracteres españoles → ASCII legible
TRANSLITERACION = str.maketrans(
    'áéíóúÁÉÍÓÚàèìòùÀÈÌÒÙäëïöüÄËÏÖÜâêîôûÂÊÎÔÛñÑ¿¡«»',
    'aeiouAEIOUaeiouAEIOUaeiouAEIOUaeiouAEIOUnN?!  '
)

ANCHO = 32          # Caracteres por línea de la QR701

ESC             = b'\x1b'
GS              = b'\x1d'
FS              = b'\x1c'
INIT            = ESC + b'\x40'
CANCELAR_CHINO  = FS  + b'\x2e'
CHARSET_WESTERN = ESC + b'\x52\x00'
ALIGN_LEFT      = ESC + b'\x61\x00'
ALIGN_CENTER    = ESC + b'\x61\x01'
BOLD_ON         = ESC + b'\x45\x01'
BOLD_OFF        = ESC + b'\x45\x00'
FEED            = b'\n'

def transliterar(texto: str) -> str:
    return texto.translate(TRANSLITERACION)

def _qr_nativo(url: str, size: int = 5) -> bytes:
    """Genera comando ESC/POS para QR nativo (modelo 2)."""
    data = url.encode('ascii')
    n    = len(data) + 3
    nL   = n & 0xFF
    nH   = (n >> 8) & 0xFF
    cmd  = GS + b'\x28\x6b\x04\x00\x31\x41\x32\x00'          # modelo 2
    cmd += GS + b'\x28\x6b\x03\x00\x31\x43' + bytes([size])   # tamaño módulo
    cmd += GS + b'\x28\x6b\x03\x00\x31\x45\x31'               # corrección M
    cmd += GS + b'\x28\x6b' + bytes([nL, nH]) + b'\x31\x50\x30' + data
    cmd += GS + b'\x28\x6b\x03\x00\x31\x51\x30'               # imprimir
    return cmd


class Impresora:
    """Gestiona la conexión con la impresora térmica QR701 por UART."""

    def __init__(self, config: dict):
        self.puerto   = config.get('puerto',   '/dev/serial0')
        self.baudrate = config.get('baudrate', 9600)
        self.conexion = None
        if not SERIAL_DISPONIBLE:
            print("[Impresora] Modo simulación activo.")
            return
        self._conectar()

    def _conectar(self):
        try:
            self.conexion = serial.Serial(self.puerto, self.baudrate, timeout=1)
            self.conexion.write(INIT + CANCELAR_CHINO + CHARSET_WESTERN)
            time.sleep(0.1)
            print(f"[Impresora] Conectada en {self.puerto} a {self.baudrate} bps.")
        except Exception as e:
            raise ConnectionError(f"[Impresora] No se pudo conectar en {self.puerto}: {e}")

    # ------------------------------------------------------------------ #
    # Primitivas internas                                                  #
    # ------------------------------------------------------------------ #
    def _escribir(self, data: bytes):
        if self.conexion and self.conexion.is_open:
            self.conexion.write(data)

    def _feed(self, n: int = 1):
        self._escribir(FEED * n)

    def _linea_centrada(self, texto: str, bold: bool = False):
        self._escribir(ALIGN_CENTER)
        if bold: self._escribir(BOLD_ON)
        self._escribir(transliterar(texto).encode('ascii', errors='replace') + b'\n')
        if bold: self._escribir(BOLD_OFF)

    def _separador(self):
        self._escribir(ALIGN_LEFT)
        self._escribir(b'-' * ANCHO + b'\n')

    def _qr(self, url: str, size: int = 5):
        self._escribir(ALIGN_CENTER)
        self._escribir(_qr_nativo(url, size))

    # ------------------------------------------------------------------ #
    # API pública                                                          #
    # ------------------------------------------------------------------ #
    def imprimir(self, texto: str):
        """Imprime una premisa narrativa alineada a la izquierda con ajuste
        automático de línea (textwrap). Usa 4 saltos al final para que la
        última línea salga completamente de la cabeza de impresión antes de
        arrancar el papel (la QR701 tiene ~30 mm de distancia cabeza-borde).
        Llamado desde salidas.py para todas las premisas."""
        if not SERIAL_DISPONIBLE:
            print(f"[Impresora] Simulación: {texto}")
            return
        if not self.conexion or not self.conexion.is_open:
            print("[Impresora] ERROR: conexión no disponible.")
            return
        try:
            limpio   = transliterar(texto)
            ajustado = textwrap.fill(limpio, width=ANCHO)
            self._feed(2)
            self._escribir(ALIGN_LEFT)
            self._escribir(ajustado.encode('ascii', errors='replace'))
            self._feed(6)           # 6 saltos: asegura que el texto salga completamente de la carcasa
            time.sleep(0.5)
            print("[Impresora] Texto enviado.")
        except Exception as e:
            print(f"[Impresora] ERROR al imprimir: {e}")

    def imprimir_centrado(self, texto: str):
        """Imprime una sola línea centrada, sin ajuste de línea automático.
        Pensado para mensajes cortos de sistema (máx. 32 caracteres).
        No se usa actualmente desde salidas.py; disponible para uso futuro."""
        if not SERIAL_DISPONIBLE:
            print(f"[Impresora] Simulación centrado: {texto}")
            return
        if not self.conexion or not self.conexion.is_open:
            return
        try:
            self._feed(1)
            self._linea_centrada(texto)
            self._feed(3)
            time.sleep(0.5)
        except Exception as e:
            print(f"[Impresora] ERROR: {e}")

    def imprimir_bienvenida(self, modo=None, ip=None):
        """
        Imprime cabecera de bienvenida con QR del portal.
        Detecta el modo de red igual que la e-ink.

        Si no se le pasan `modo` e `ip`, los detecta por su cuenta. El anuncio
        del primer arranque los captura ANTES de anunciar, para que el modo no
        pueda cambiar entre la detección y la impresión, y los pasa aquí; misma
        firma que `PantallaEInk.mostrar_bienvenida`.
        """
        if not SERIAL_DISPONIBLE or not self.conexion or not self.conexion.is_open:
            return
        try:
            if modo is None:
                from modules.netinfo import get_wifi_mode, get_ip
                modo = get_wifi_mode()
                ip   = get_ip()

            self._feed(2)
            self._linea_centrada("La asombrosa maquina", bold=True)
            self._linea_centrada("de generar historias", bold=True)
            self._separador()
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

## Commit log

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2026-05-25 Prueba de commit de stl
    [Linterna logo IES.stl]
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2026-05-27 Se resuelven los problemas con AP no automático
    [eink.py, impresora.py]
2026-05-28 fix: robustez ronda 1 — locks concurrencia + BUSY timeout
    - generador.py: threading.Lock en generar_frase() para atomizar
    comprobación + pop(); evita IndexError si botón y portal coinciden
    - eink.py: threading.RLock en EPD_4IN2 serializa acceso SPI/GPIO;
    _esperar_idle() lanza TimeoutError en vez de continuar silenciosamente
    - main.py: maneja retorno None de generar_frase() como frases agotadas
    [eink.py, generador.py]
2026-05-28 fix: sudoers con propietario root en setup_sd.sh
    mv preserva uid del scp (1000); usar install -o root -g root -m 440
    para garantizar que sudo no rechace el fichero en producción.
2026-05-28 fix(ronda-2): recarga generador al cambiar perfil + perfil vacío descriptivo
    - main.py: al_cambiar_perfil() recarga Generador en caliente cuando el
    portal web cambia el perfil activo (#5.5). Registra callback
    registrar_callback_cambiar_perfil en el portal. Captura ValueError
    además de FileNotFoundError al iniciar Generador.
    - generador.py: _cargar_lista() lanza ValueError con mensaje explicativo
    si el .txt existe pero está vacío (#5.8). Evita que el sistema arranque
    silenciosamente con un perfil inutilizable.
    [generador.py]
2026-05-28 fix(ronda-3): escritura atómica, timeout TTS, mpg123 check, execv→systemctl
    - portal.py: guardar_premisas() usa tempfile + os.replace (atómico).
    Evita corrupción del .txt si la SD se llena o hay corte de luz durante
    la escritura. Mismo patrón que guardar_config() (#R3-A).
    - audio.py: asyncio.wait_for(timeout=15) en comunicar.save() para que
    edge-tts no cuelgue si la red es lenta o está caída (#R3-B).
    check=True en subprocess.run de mpg123: si el device ALSA no existe
    o falla, CalledProcessError se propaga y hablar() cae al fallback
    espeak-ng (#R3-C).
    - main.py: sustituye os.execv() por subprocess.Popen(systemctl restart)
    + sys.exit(0). os.execv hereda el FD del socket F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
    [audio.py, portal.py]
2026-05-28 fix(ronda-4): secret_key por dispositivo, path traversal, setup_completado=false
    - portal.py: app.secret_key ya no es la cadena hardcoded compartida.
    Portal.__init__() lee 'flask_secret' de config.json; si no existe,
    genera secrets.token_hex(32) y lo persiste. Cada dispositivo tiene
    su propia clave de sesión (#R4-A).
    - portal.py: anadir_premisa y borrar_premisa validan 'perfil' contra
    get_perfiles() antes de acceder al sistema de ficheros. borrar_premisa
    también valida 'tipo' (faltaba). Evita path traversal vía API (#R4-B).
    - portal.py: nuevo_perfil añade guard de contención de ruta —
    os.path.abspath(ruta).startswith(PERFILES_DIR + os.sep) —
    antes de crear el directori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
    [portal.py]
2026-05-28 fix(impresora): 4 saltos al final de imprimir() + docstrings claros
    - impresora.py: _feed(2)→_feed(4) al final de imprimir(). La QR701
    tiene ~30 mm entre cabeza de impresión y borde de carcasa; con 2
    saltos el último renglón quedaba dentro y se cortaba al arrancar el
    papel. 4 saltos lo dejan completamente fuera.
    - impresora.py: docstrings en imprimir() e imprimir_centrado() que
    aclaran el propósito de cada uno. imprimir() = premisas, ajuste
    automático, llamado desde salidas.py. imprimir_centrado() = mensajes
    cortos de sistema, una línea centrada, no se usa aún.
    - config.json: impresora.activada→false. El config del repo es la
    plantilla para Pis nuevas; no debe asumir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
    [impresora.py]
2026-05-28 fix(impresora): 6 saltos al final de imprimir() para mayor margen
    [impresora.py]
2026-05-28 fix(audio): keep-alive MAX98357A elimina chasquido en cada premisa
    El MAX98357A entra en shutdown al instante en que BCLK (reloj I2S) se
    detiene — es decir, cada vez que mpg123 termina. Al reactivarse produce
    un chasquido audible antes de cada premisa.
    Solución en dos capas:
    - audio.py: _iniciar_keepalive() lanza un hilo daemon que alimenta
    /dev/zero a plug:dmixed (silencio digital continuo). El reloj I2S
    nunca para; el único chasquido ocurre al arrancar el sistema, no en
    cada premisa. Requiere aplay (alsa-utils, ya instalado).
    - setup_sd.sh: asound.conf cambia pcm.dmixed de 'type hw' a 'type dmix'
    (mixer por software). Permite que aplay y mpg123 usen el dispositivo
    simultáne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
    [audio.py]
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2026-05-28 Fix en robustez código del botón
    [boton.py]
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2026-06-16 setup_sd: SSH ControlMaster para eliminar prompts de contraseña
    Todas las llamadas ssh/scp reutilizan la primera conexión autenticada.
    Solo el paso 0 (ssh-copy-id) puede pedir contraseña, y solo en el
    primer setup cuando la clave aún no está instalada en la Pi.
2026-06-19 Robustez WiFi: 9 fixes de auditoría Opus 4.8
    - DNS hijacking en dnsmasq-shared.d/captive.conf: todo dominio resuelve
    a 10.42.0.1 en modo AP (sin esto iOS/Android no disparan el portal)
    - storymaker-captive.py: guard 403 en /conectar fuera de modo AP,
    validación SSID (≤32B) y PSK (8-63 chars), rsplit para SSIDs con ':',
    timeout nmcli up 30→45s, maxIntentos JS 20→30, mensaje UX AP dropout
    - storymaker-wifi.sh: rescate AP por botón al arrancar (GPIO5 pulsado),
    || true en asignaciones con pipe (evita abort por set -euo pipefail),
    detección CONNECTIVITY (portal/limited/none) en log, verificación real
    del AP antes de marcar /run/storymaker-ap-mode
    - netinfo.get_ip(): excluir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
    [netinfo.py]
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2026-10-03 UX: botón arranque→AP, captivo mejorado, factory reset, e-ink post-WiFi
    - Botón mantenido 3s al arranque fuerza modo AP con feedback LED progresivo
    (parpadeo lento durante cuenta, rápido al confirmar)
    - E-ink actualiza de pantalla AP a pantalla portal tras conectar WiFi
    (captivo reinicia historias.service con 5s de delay)
    - Portal cautivo: ojo en campo contraseña, redirección automática al
    formulario con aviso en rojo si la contraseña es incorrecta
    - Portal principal: botón apagado en cabecera, factory reset en /setup,
    ojo en campo PIN de login
    - Generador: eliminada coma incorrecta entre protagonista y conflicto
    - crear_imagen.sh: modo --local con pre-encogido de partició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
    [boton.py, generador.py, portal.py]
2026-10-03 deploy.sh: incluir storymaker-captive.py en el despliegue automático
    El portal cautivo vivía fuera del tar de firmware y requería copia
    manual. Ahora deploy.sh lo sube a /usr/local/bin/ y reinicia su
    servicio como paso 4/5, igual que hace con historias.service.
2026-10-03 Primer arranque multi-salida: e-ink, voz y impresora anuncian la URL del portal
    - main.py: en modo setup, intenta e-ink + Audio (edge-tts/espeak) + impresora
    independientemente de la config guardada; detecta cambio AP→cliente y
    re-anuncia; _modo_red capturado antes del anuncio para evitar race condition
    - eink.py: mostrar_bienvenida() acepta modo/ip opcionales (evita doble nmcli)
    - limpiar_montada.sh: reset completo de hardware al crear imagen distributable
    - crear_imagen.sh: sfdisk en lugar de parted (no interactivo en Fedora/Nobara)
    - config.json: volumen audio por defecto 50
    [eink.py]
2026-10-03 Importación de premisas en bloque desde .txt vía portal web
    Asistente de tres pasos en /importar (formulario → revisión → confirmación)
    para que alguien sin perfil técnico pueda poblar un perfil desde archivos de
    texto. Nada se escribe hasta confirmar.
    - modules/importador.py: decodifica UTF-8/BOM y reintenta CP1252 y Latin-1
    (los .txt llegan de Word y del Bloc de notas), normaliza espacios duros y
    CRLF, deduplica sin distinguir mayúsculas y no toca la puntuación. Copia
    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
2026-10-03 Perfil «adultos»: 50 premisas por lista para taller abierto
    Segundo perfil de serie, junto a 1eso, para que el dispositivo salga de
    fábrica con dos registros distintos. Pensado para talleres de escritura
    creativa con adultos: detonantes con más carga dramática, protagonistas
    con oficio y conflictos de dilema moral.
    Las tres listas tienen 50 entradas exactas, así que el perfil rinde 50
    combinaciones completas (el Generador se limita por la lista más corta).
    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
2026-10-03 Contraseña SSH propia por dispositivo en el primer arranque
    La imagen distribuible es pública, así que la contraseña UNIX que viaja
    dentro era una credencial compartida por todas las unidades. Y con el
    `NOPASSWD: ALL` que Raspberry Pi OS deja en /etc/sudoers.d/010_pi-nopasswd,
    entrar por SSH equivalía a ser root: con eso se leen en claro los `psk=` de
    /etc/NetworkManager/system-connections/, es decir la clave WiFi de la red
    donde esté el dispositivo. El asistente de primer arranque ahora exige una
    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
2026-10-03 limpiar_pi.sh: el borrado del WiFi mataba la limpieza a mitad
    `nmcli connection delete` sobre el perfil WiFi activo tumba la interfaz, y
    con ella la sesión SSH desde la que corre el script. Estando ese borrado en
    el paso 1, los pasos 2 a 6 no llegaban a ejecutarse cuando se invoca como
    lo hace crear_imagen.sh:
    ssh "$PI" 'bash -s' < limpiar_pi.sh
    Es decir, las imágenes generadas con ese flujo podían salir con las claves
    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
2026-10-03 limpiar_montada.sh: forzar SHA512 al reescribir la contraseña
    El script corre en el ordenador de desarrollo, no en la Pi, y sobrescribe el
    /etc/shadow del rootfs montado. El chpasswd de la distribución anfitriona
    puede generar por defecto un hash yescrypt; si la libcrypt de la Pi no lo
    admitiera, la contraseña de fábrica documentada no funcionaría en una imagen
    recién flasheada. SHA512 ($6$) la entienden todas.
    Importa porque crear_imagen.sh ejecuta este script en modo --local, de modo
    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
2026-10-03 releases: documentar el proceso real de publicación y el SHA256 de v2026-10-03
    El README anterior describía una descarga imposible: remitía a una sección
    Releases que estaba desactivada en el repo, y el proceso nunca se había
    ejecutado completo ni una vez (cero tags, cero releases).
    Queda escrito el orden verificado hoy, incluidos los tres puntos que no son
    evidentes y que se han descubierto haciéndolo: que hay que verificar la
    tarjeta antes de capturar, que --local resetea el hardware y limpiar_pi.sh
    no, y que los push-mirrors replican refs pero no adjuntos de release.
    También las credenciales de fábrica y por qué son públicas a propósito.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
2026-10-03 deuda-tecnica: blob huérfano en Codeberg y divergencia de los scripts de limpieza
    Dos cosas descubiertas durante la release de v2026-10-03 que no están
    resueltas y que no se deducen del código.
2026-10-03 deuda-tecnica: rebajar el mínimo de contraseña SSH a 6 caracteres
    Pedido tras probar el primer arranque de v2026-10-03 desde la imagen
    publicada: 8 caracteres resultan incómodos de teclear en el asistente.
    Queda anotado también qué hay que tocar (dos sitios, porque el ayudante
    revalida) y la contrapartida: el ataque realista es fuerza bruta por SSH
    desde la propia red, así que la rebaja debería ir acompañada de limitación
    de intentos.
2026-10-03 deuda-tecnica: sin internet se pierden 15 s por frase esperando a edge-tts
    audio.py elige el motor TTS mirando sólo si existe el binario de edge-tts,
    nunca si hay red, aunque el mensaje de arranque sugiera lo contrario. Sin
    internet eso significa agotar el timeout de 15 s en cada premisa antes de
    caer a espeak-ng.
    Importa porque los talleres en zonas sin cobertura son un escenario de uso
    previsto. netinfo.py ya detecta el modo de red y podría decidirlo de
    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
2026-10-03 deuda-tecnica: descartada la rebaja de la contraseña SSH a 6 caracteres
    Decidido mantener el mínimo de 8 y no tocar nada.
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2026-10-03 limpieza: borrar los restos de despliegue que quedan en /tmp
    En Raspberry Pi OS /tmp está en disco, así que lo que quede ahí acaba dentro
    de la imagen distribuible. Un despliegue abortado deja, por ejemplo,
    /tmp/storymaker-captive.py.
    En frío se vacía /tmp del todo, que es lo correcto cuando no hay nada en
    marcha. En caliente sólo se borran los restos conocidos: el portal y el TTS
    usan /tmp mientras el servicio corre.
2026-10-03 limpieza: fijar el perfil activo de fábrica en la imagen
    Los scripts reseteaban PIN, setup_completado, flask_secret y hardware, pero no
    perfil_activo. La imagen heredaba el perfil que estuviera seleccionado en el
    dispositivo usado para capturarla: una dependencia silenciosa de qué Pi se
    tuviera a mano. Detectado al revisar la tarjeta de la máquina de la impresora,
    que tenía 'adultos' activo, cuando la imagen anterior se publicó con '1eso'.
    Si el perfil de fábrica no existiera se deja el que haya y se avisa, en lugar de
    apuntar a una carpeta inexistente: el Generador lanzaría FileNotFoundError y el
    dispositivo arrancaría sin poder generar.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
